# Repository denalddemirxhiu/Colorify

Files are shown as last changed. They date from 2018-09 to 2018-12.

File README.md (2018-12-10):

# Colorify Build Instructions

## Introduction
Colorify is a creative project that allows the user to scan colours in the environment with the help of a colour sensor. The project is meant to detect colours so that they can be used for illustration and graphic design purposes. At the end of this instructive tutorial, we will be able to detect colours in the environment as well as display the colour readings in RGB and HEX format for the user to use freely. Below, the diagrams provide a visual way on how the project works, and how it might be integrated with a database and a mobile application for further development.

### System Diagram
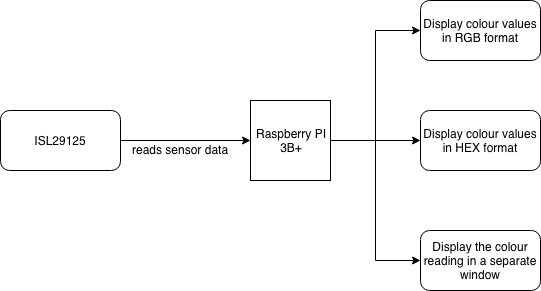
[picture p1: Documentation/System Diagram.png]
System Diagram


### Capstone UML Diagram
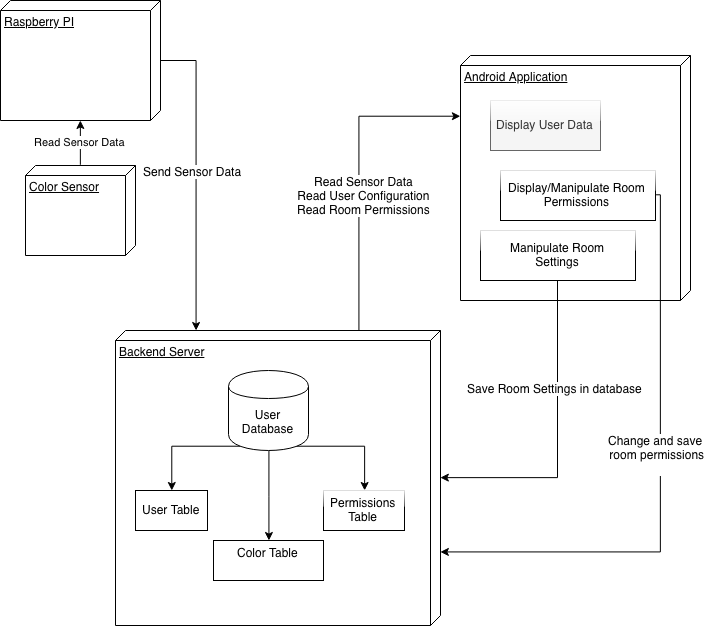
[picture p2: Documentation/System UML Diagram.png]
Capstone UML Diagram


#### Helpful Skills for this project
 - Soldering
 - Raspberry PI knowledge
 - I2C knowledge
 - Python knowledge
 - Breadboarding and wiring knowledge

## Bill of Materials
The devices and components that we will need to complete the project, as well as the sources where they can be found are provided below for reference

| Item Name | Source/Supplier |
|---|---|
| Raspberry Pi 3B+ Starter Kit | CanaKit - https://www.canakit.com/raspberry-pi-3-model-b-plus-starter-kit.html |
| ISL29125 RGB Light Sensor | SparkFun - https://www.sparkfun.com/products/12829 |
| Breadboard Jumper Wires | HaoBase/Amazon - https://www.amazon.ca/gp/product/B01DLKLL6C/ref=ox_sc_act_title_1_1_1?smid=A3F3WC2XXCSM1P&psc=1 |
| Bernzomatic Rosin Core Solder (Lead free) | Canadian Tire - http://www.canadiantire.ca/en/pdp/bernzomatic-rosin-core-solder-0586000p.html#srp |
| Wire Stripper | Ideal/Amazon - https://www.amazon.ca/Ideal-45-120-Stripper-10%C3%9018-Stranded/dp/B000JKWVXA |
| Breadboard | Canada Robotix - http://www.canadarobotix.com/solderless-breadboard/830-point-breadboard |
| Soldering Iron | Canadian Tire - http://www.canadiantire.ca/en/pdp/weller-25w-soldering-iron-kit-0586309p.html#srp |
| Digital Multimeter | Canadian Tire - http://www.canadiantire.ca/en/pdp/autoranging-digital-multimeter-0520052p.0520052.html |
| Clear Acrylic 12"x24" | Johnston Industrial - http://www.johnstonplastics.com/toronto/ |
| 40-pin Stackable Header | Adafruit - https://www.adafruit.com/product/1979 |
| Arduino Stackable Header Kit |  Sparkfun - https://www.sparkfun.com/products/10007 |
| Computer Monitor |  Bestbuy - https://www.bestbuy.ca/en-ca/product/hewlett-packard-hp-21-5-fhd-60hz-7ms-gtg-ips-led-monitor-22vc-black-22vc/10514441.aspx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 |
| Wired Keyboard |  Bestbuy - https://www.bestbuy.ca/en-ca/product/mmnox-mmnox-usb-keyboard-op004-english-op004/10383781.aspx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 |
| Wired Mouse | Bestbuy - https://www.bestbuy.ca/en-ca/product/rapoo-optical-mouse-n1130-white/12966363.aspx? |

Note: The Raspberry Pi 3B+ Starter Kit comes with everything you need such as:
 - Standard Power Supply
 - 16 GB microSD card
 - Black enclosure
 - microSD USB adapter
 - HDMI Cable

If you would like to purchase the above items separately make sure they are bought from a reliable source!

For a more detailed bill of materials with the component prices, sources, part numbers you can click [here](https://github.com/denalddemirxhiu/Colorify/blob/master/Documentation/Colorify%20Budget.xlsx). The total amount of money needed to be spent for this project is about $230 (CAD).

## Time Commitment
This project should not take more than a weekend to be completed after all the components have been gathered. Overall, it should take about 5-7 hours to complete (considering that the PCB has been printed successfully, otherwise the PCB should take about a half-day to be printed). This can be divided in these steps:
 - Raspberry PI setup (2 - 3 hours)
 - Sensor Soldering (30 mins)
 - PCB Soldering with stackable headers (45 mins)
 - Enclosure printing (laser cutting) and assembly (45 mins)
 - Putting it all together (1 hour)
 - Verifying that everything works (30 mins)

## Setting up the Raspberry PI 
For this portion you will need a monitor compatible with HDMI, a wired keyboard (USB) and a wired mouse (USB).
 1. Download the latest version of Raspbian. The image for flashing the Raspbian OS in the Raspberry PI can be found [here](https://www.raspberrypi.org/downloads/raspbian/)
 2. Format the microSD card by plugging it in your computer of choice and use the software found [here](https://www.sdcard.org/downloads/formatter_4/index.html)
 3. Use a software such as [Etcher](https://www.balena.io/etcher/) or [Win32DiskImager](http://sourceforge.net/projects/win32diskimager/) to flash the OS image to the microSD card.
 4. After this process has been finished successfully plug the microSD card in the Raspberry PI 3B+, connect the HDMI cable, the mouse, and the keyboard and power the device on.
 5. After finishing the setup and while on the Desktop we need to change the I2C and VNC interfaces to enabled. This can be done by going to the Start Menu->Preferences->Raspberry Pi Configuration->Interfaces, then set VNC to enabled and I2C to enabled
 
 After these steps have been followed carefully, we can move on to the mechanical assembly.
 
## Mechanical Assembly
To get started, we need to solder the pins to the ISL29125 RGB Light sensor. To do so we need to have 5 pins for each of the holes in the sensor and we need to have the soldering equipment ready. The soldering process needs to be careful as to not short any of the pins with each other which damage the sensor. After the pins have been soldered to the sensor, it should look something like this:

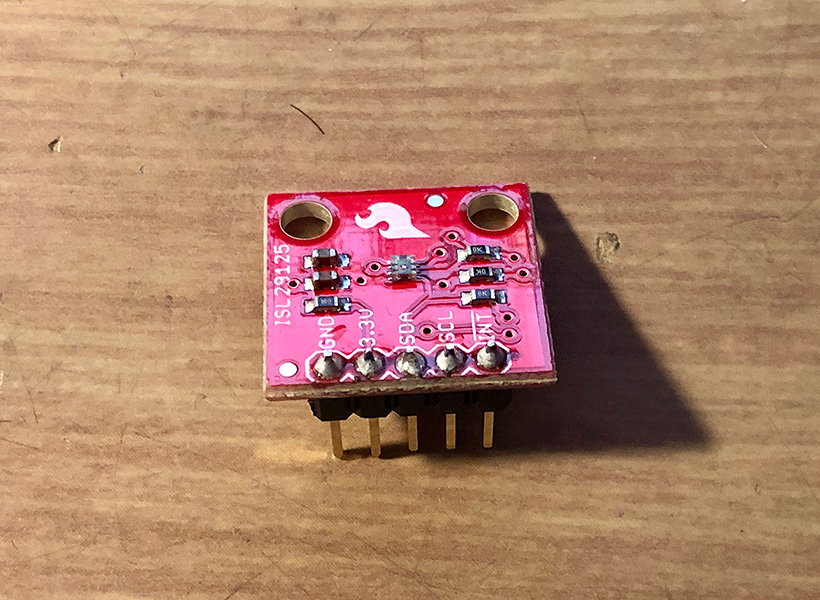
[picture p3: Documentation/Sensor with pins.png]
Sensor Soldered


Secondly, we need to connect the sensor to the Raspberry PI 3B+ to test if it works properly. It is a good idea to power down the Raspberry PI before continuing with this step. First, we place already soldered sensor in the breadboard. Using [this](https://www.theengineeringprojects.com/wp-content/uploads/2018/07/introduction-to-raspberry-pi-3-b-plus-2.png) diagram, we are going to make the appropriate connections from the sensor to the pin headers of the Raspberry PI. For the connections we are going to use the Male-to-Female jumper wires. Since the sensor has labeled pins, we are going to make these connections:
 - PIN 1 (3.3V) of the Raspberry PI should be connected to the pin labeled as 3.3V in the sensor
 - PIN 6 (GND) of the Raspberry PI should be connected to the pin labeled as GND in the sensor
 - PIN 3 (SDA) of the Raspberry PI should be connected to the pin labeled as SDA in the sensor
 - PIN 5 (SCL) of the Raspberry PI should be connected to the pin labeled as SCL in the sensor
 
After the appropriate connections have been made, the wiring should look something like this:

Sensor Wiring

After powering on the Raspberry PI we need to verify that the sensor is being recognized. With the wiring still in place launch the terminal window and type this command:

      sudo i2cdetect -y 1
 
The command will display the sensor in a table like this:
i2cDetect

NOTE: If you don't see the sensor's I2C address in the table (0x44), then verify the connections, verify that I2C Interface is enabled, and as a final resort restart the Raspberry PI.

After all the steps in this section have been verified, you can move on to the next step.

## PCB Soldering
The PCB design used to print the PCB can be found [here](https://github.com/denalddemirxhiu/Colorify/blob/master/Documentation/ISL29125.fz.fzz). The design was made using [Fritzing](http://fritzing.org/home/). To print the PCB you need to convert the provided files into Gerber files and send them to any production facility, as the files are industrially universal.

After the PCB has been printed, we are going to solder the 5 pin stackable header, and the 20 pin stackable header into the PCB. Since none of the stackable headers we have is 5-pin we are going to break one of them into a 5-pin, which can easily be done using a set of pliers. After we do that, we are going to solder the VIAs (small holes with connections on both sides). To do that we are going to use some hookup wire, which we are going to strip and place in the VIAs. After verifying that the VIAs have been soldered, we can insert the stackable headers in the appropriate pins. The 5-pin header is going to be inserted in the side where the labels are found (GND, 3.3V, SDA, SCL). The 40-pin header is going to be inserted on the other side with the pins facing the side the labels are found. After the pins have been soldered we can verify if the connections have been correctly made by using a multimeter. After all the work has been finished the PCB should look something like this:

### PCB Soldered Front
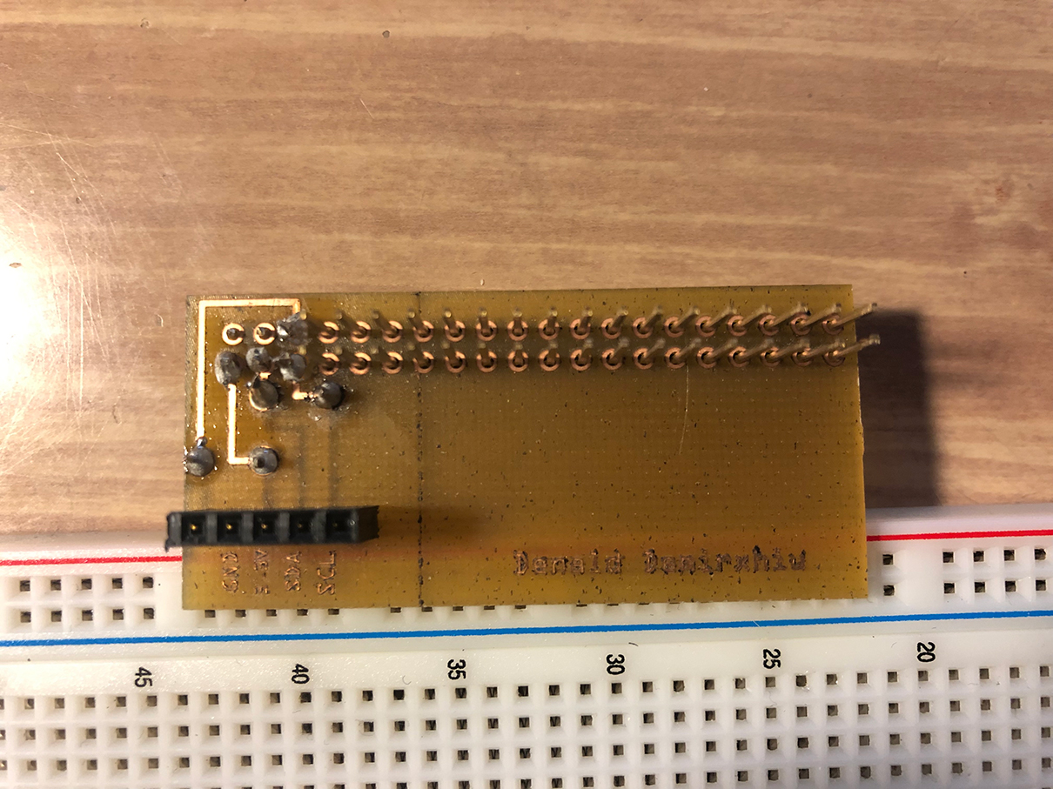
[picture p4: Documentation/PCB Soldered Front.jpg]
PCB Front


### PCB Soldered Back
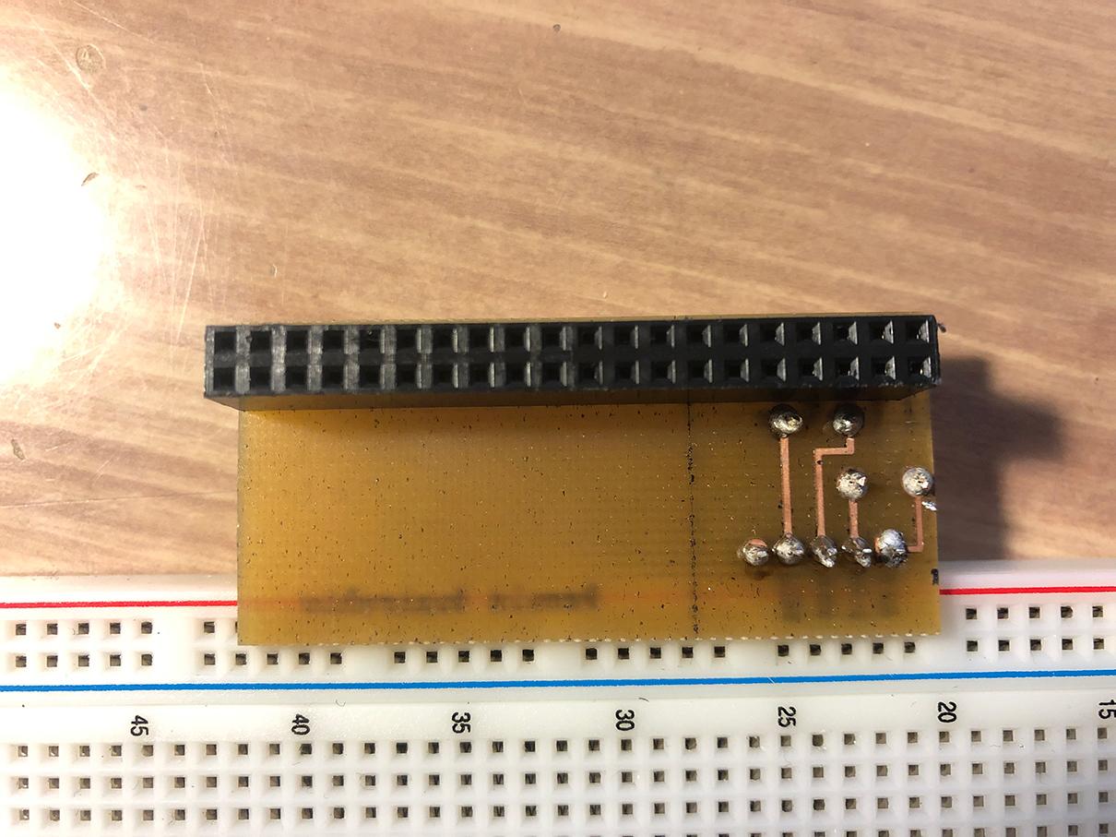
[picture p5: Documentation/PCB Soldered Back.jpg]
PCB Back


## Power Up
After the PCB has been soldered correctly and the sensor has been verified to work with the Raspberry PI, it is time for the power up portion. With the Raspberry PI powered off, the PCB is going to be mounted on the Raspberry PI using the 40-pin stackable header and the sensor is going to be mounted on the 5-pin header on the PCB. After the mounting process is done it should look something like this:

Mounted PCB Sensor

The case that comes with the Raspberry PI 3B+ can fit the PCB board mounted in it. For that reason we don't need to make any specific enclosure for it.

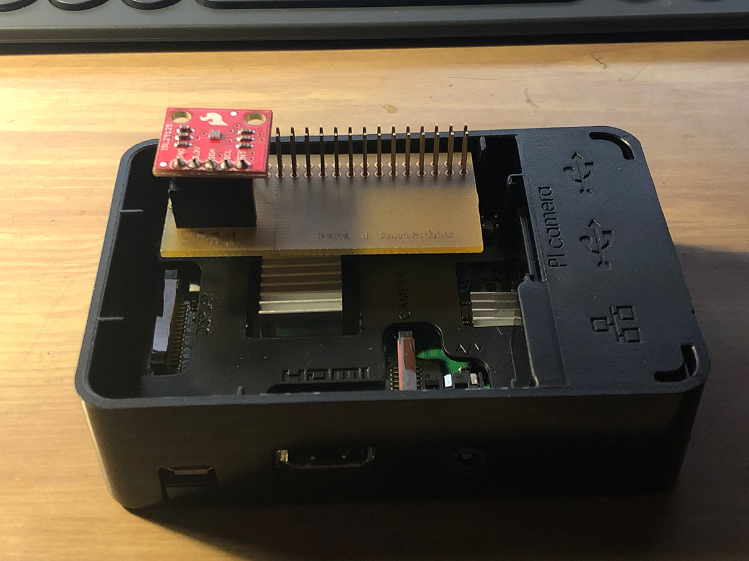
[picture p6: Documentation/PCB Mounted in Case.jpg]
Case with Sensor


After the PCB and the sensor is mounted on the board, it can be powered up and verified that the Raspberry PI recognizes the sensor using the same i2cdetect command as above:

       sudo i2cdetect -y 1

Using the supplied script that can be downloaded from [here](https://github.com/denalddemirxhiu/Colorify/blob/master/Documentation/readSensor.py), you can test the sensor reading actual colour values from the environment. The code uses Python 3 and can be compiled and run using the default python editor in the Raspberry PI, Thonny. If everything has been done correctly you should see an output on the screen like this:

Sensor Output

Note: For the sensor to read different colour values you might want to use a plastic piece of paper (preferrably with colour), however if it is transparent you can use a Sharpie with some different colours to simulate different colour readings. This is one way to test if the sensor is reading values correctly

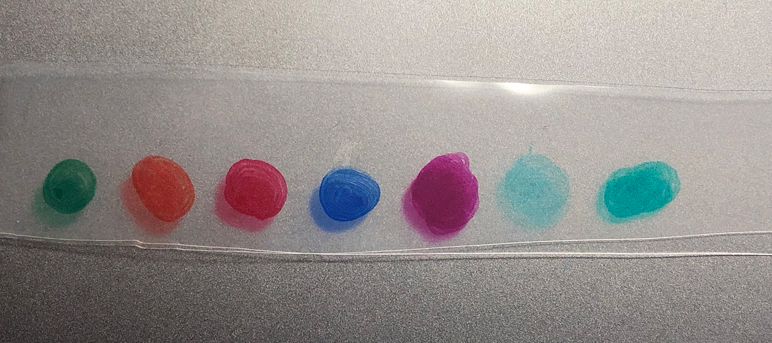
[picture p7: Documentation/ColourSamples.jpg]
Colour samples


## Enclosure

The enclosure for this project does not require any custom case to be made. In fact the case that comes with the Raspberry PI 3B+ can hold the PCB and the sensor intact. The only part that is needed for this enclosure is the top part which ensures that the sensor is kept intact with no contact to materials that might damage it. The enclosure also requires a set of 4 clamps that hold everything together. Both the top enclosure sheets and the clamps are made of acrylic and can easily be laser cut in a matter of minutes. The file for the top enclosure sheets can be found [here](https://github.com/denalddemirxhiu/Colorify/blob/master/Documentation/Top%20Case%20Design%20Files.cdr) and the file for the clamps can be found [here](https://github.com/denalddemirxhiu/Colorify/blob/master/Documentation/Case%20Clamps.cdr). Both designs were made with CorelDraw X6.

The top enclosure part has 5 acrylic frames and one acrylic top that can be stacked together. To glue the components together you might use any transparent glue that you can think of, but if you can find some Liquid Cement for plastic that would work too. After the acrylic sheets have been stacked together and have been glued, the top part of the case should look something like this:

### Acrylic Top
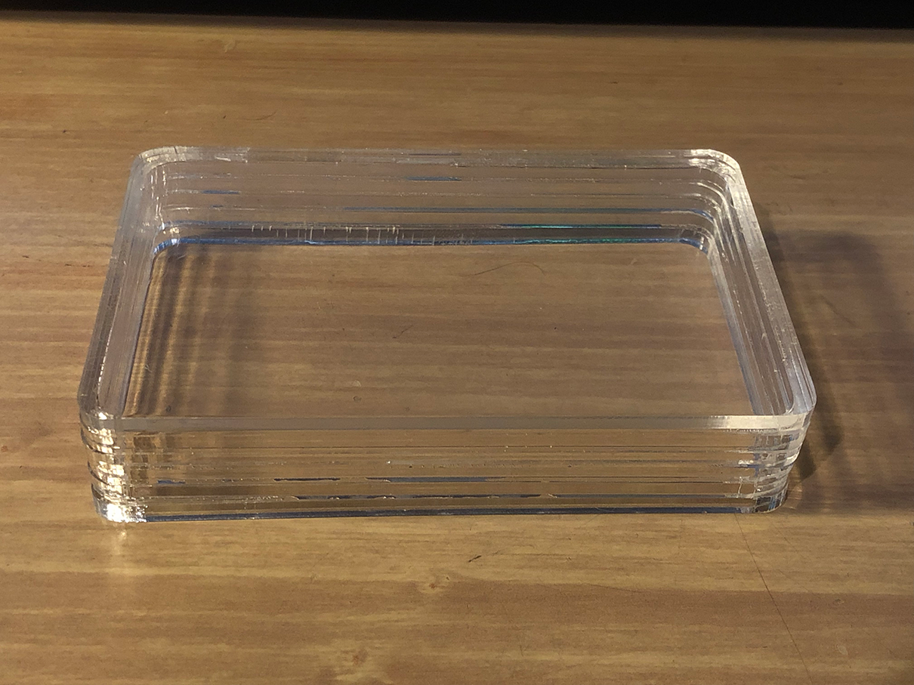
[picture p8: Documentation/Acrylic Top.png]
Top Case


## Finishing it up
By now the Raspberry PI should be in its black case that came with the Starter Kit. The PCB with the mounted sensor, will be inserted into the GPIO pins of the Raspberry PI. Next the acrylic top will be placed on the top of the case with the 4 clamps inserted on each side to support the enclosure. After all the processes above these should be the final results:

### Case with Acrylic sheets on top
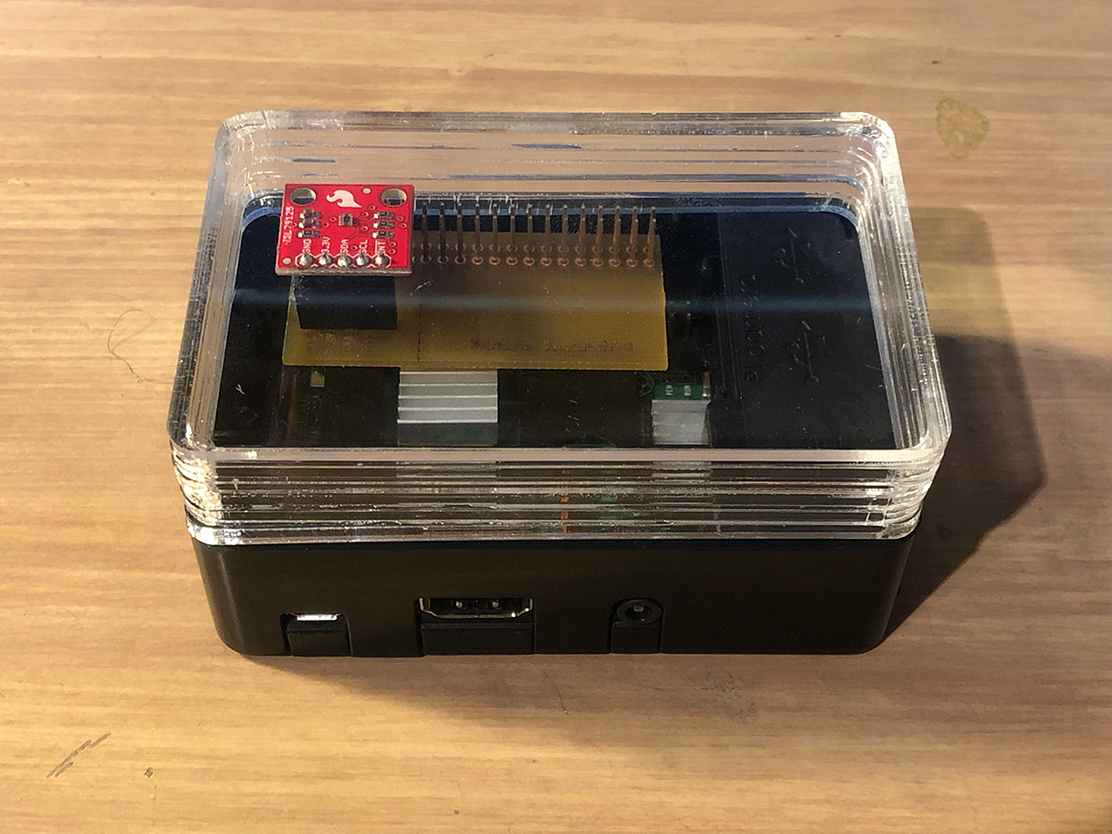
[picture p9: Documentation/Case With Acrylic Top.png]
Completed Case


### Completed Case
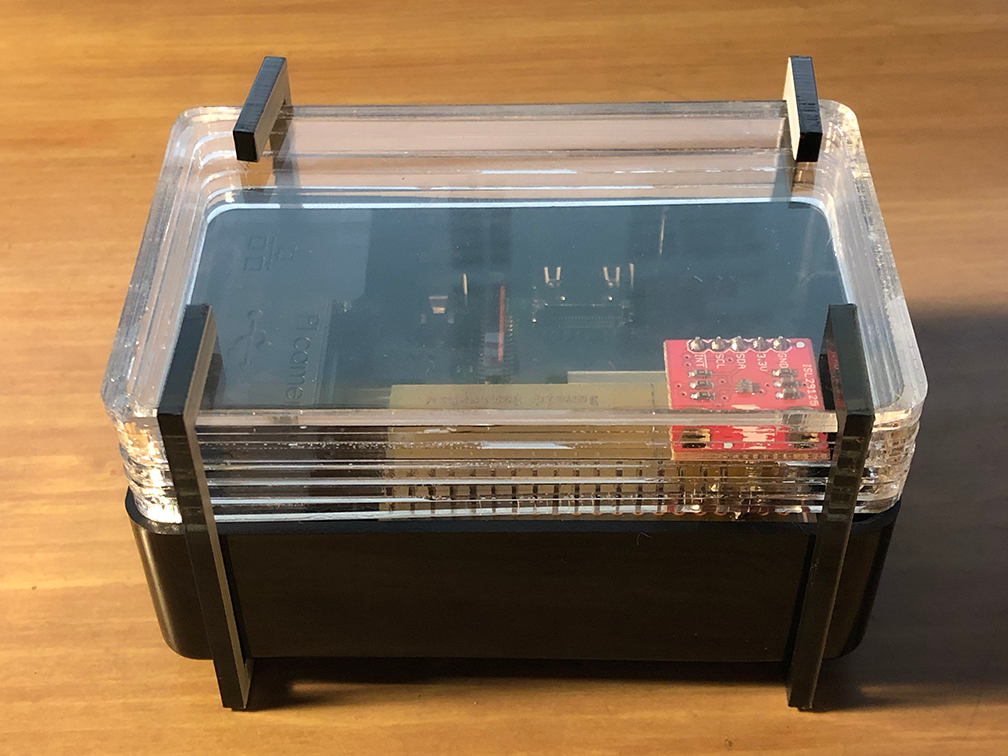
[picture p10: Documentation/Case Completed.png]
Completed Case with Clamps


## Testing
It is useful to test the hardware before testing the software side of the project. First when finishing the soldering of the PCB it is a good idea to check each connection between the appropriate pins. This part of the testing process can be performed using any conductive wire inserted in the stackable header for the pins we are going to use, and a multimeter to test if the connection is correct. If when testing the pins a open circuit is observed then the soldering should be checked and the appropriate measures should be taken.

After testing the hardware we are going to test the software side. With the sensor plugged in the PCB, which should be inserted in the Raspberry PI with the help of the stackable header, we are going to compile and run the provided software for detecting color values and displaying them. 
 - First, we need to check that the Raspberry PI can recognize the sensor mounted on the board. This can be done with the command: `i2cdetect -y 1`. If the sensor is not shown in the table output with the address 0x44 printed on the table, then the Raspberry PI cannot detect it. Make sure that the connections have been checked appropriately, the sensor is not damaged, and the I2C interface has been enabled in the Raspberry PI.
 - Second, compile and run the python code found [here](https://github.com/denalddemirxhiu/Colorify/blob/master/Documentation/readSensor.py) using Thonny. The color readings should be displayed accordingly in RGB and HEX format in the console, while the color readings should also be displayed in a separate window. If there are problems with compilation and running the code, check if the source code is correct, check if Python 3 is correctly installed in the Raspberry PI, and as a last resort restart the device.

## Resources used
 - Intersil Datasheet for ISL29125 found [here](https://www.intersil.com/content/dam/Intersil/documents/isl2/isl29125.pdf)
 - Sparkfun ISL29125 hookup guide found [here](https://learn.sparkfun.com/tutorials/isl29125-rgb-light-sensor-hookup-guide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)
 - Soldering tutorial found [here](https://www.youtube.com/watch?v=Qps9woUGkvI)

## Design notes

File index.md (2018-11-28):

# Colorify
denalddemirxhiu.github.io/Colorify

## November 27th, 2018 (Presentation)
The project was presented to the class today. The presentation can be found [here](https://github.com/denalddemirxhiu/Colorify/blob/master/Documentation/Colorify%20Presentation.pptx)

### Budget Update
There has been no budget update as of this date. The budget can be viewed [here](https://github.com/denalddemirxhiu/Colorify/blob/master/Documentation/Colorify%20Budget.xlsx)

### Project Schedule Update
The progress of the project has been going on schedule. There have been no setbacks. The next milestone is the build instructions. The project schedule can be viewed [here](https://github.com/denalddemirxhiu/Colorify/blob/master/Documentation/Capstone%20Gantt%20Schedule.mpp)

## November 20th, 2018 (Case Design)

### Designed and laser cut the acrylic top case
Since the ISL29125 sensor mounted on the PCB fits perfectly on the case that came with the Raspberry Pi 3B+, I did not have to design a case from scratch. However I needed to design the top part for the case to completely enclose the sensor without affecting the sensor's ability to obtain readings. The top part of the case was made of acrylic sheets that were laser cut and stacked on top of one another to create a simple clear enclosure. A set of clamps were designed to hold the case in place, but unfortunately due to the Prototype Lab's working hours I couldn't laser cut the clamps.

- The design files for the stacks of acrylic needed to make the top part of the case can be found [here](https://github.com/denalddemirxhiu/Colorify/blob/master/Documentation/Top%20Case%20Design%20Files.cdr)
- The design files for the clamps to hold the case in place can be found [here](https://github.com/denalddemirxhiu/Colorify/blob/master/Documentation/Case%20Clamps.cdr)

#### Acrylic Case
Acrylic Top Case

The case

### Completed Case with clamps

The completed case

### Budget Update
There has been no budget update as of this date. The project budget can be viewed [here](https://github.com/denalddemirxhiu/Colorify/blob/master/Documentation/Colorify%20Budget.xlsx)

### Project Schedule Update
The progress of the report has been going on schedule. This week the top part of the acrylic case was properly designed, laser cut and assembled. Next week the presentations are due and the following weeks the build instructions should be ready. The project schedule can be viewed [here](https://github.com/denalddemirxhiu/Colorify/blob/master/Documentation/Capstone%20Gantt%20Schedule.mpp)

## November 13th, 2018

### PCB Soldered and Mounted on the board
The PCB was re-designed, updated, printed and then soldered with the stackable headers in the respective places. The PCB was checked for problems with a multimeter, the sensor was checked if it was working with the PCB mounted on the Raspberry PI, and verified that the program worked while the sensor was mounted on the PCB. This can be seen in the following pictures:

PCB with the Sensor

PCB mounted on the Raspberry Pi

### Sensor Readings and Output
Using Python 3 the sensor readings were obtained and printed on the terminal in RGB format and in HEX format. The colour readings from the sensor are displayed in a window with the respective colour. The sensor readings are not fully accurate because the way that the Red, Green, and Blue photoresistors are placed in the sensor appear to be in a box array where blue and red are always adjacent to each-other, but the green photoresistors are all together. The datasheet also provided this explanation to why the colour readings of the green photoresistors are the most accurate, while the red and blue ones are not always accurate. Furthermore, the sensor is affected by light intensity from direct light coming from a light source. One solution to this might be using an acryllic case that reflects some of the light and lets a portion of the light hit the sensor, but that is not definitive. More research has to be done in that matter. 

The respective pages from the datasheet that display information on this matter are 1, 5, and 15. The datasheet can be viewed [here](https://www.intersil.com/content/dam/Intersil/documents/isl2/isl29125.pdf)

#### Colour samples used
These are colour samples I made to demonstrate the sensor reading colours.

ColourSamples

#### Displaying Color Readings in the Terminal and the Window
Displaying Colour Readings

### Reading the sensor data
To read the sensor data I used the open-source code obtained from [here](https://github.com/bhaskar-anil429/ISL29125/blob/master/ISL29125.py) and modified it to fit my needs. The problem with my sensor was that there was no library to read data from it; the resources from the company that produced the sensor were scarce. The only provided libraries were for Arduino, which are not compatible with the Raspberry PI. Therefore, I used [bhaskar-anil429](https://github.com/bhaskar-anil429)'s source code to work with. I tested the code first and after proving that it worked I made the necessary changes to fit the needs of my project. The program that I designed reads the color values continuously and prints them in a HEX and RGB format, as well as displaying them on another window. The source code for the Python script can be viewed [here](https://github.com/denalddemirxhiu/Colorify/blob/master/Documentation/readSensor.py)

### Budget Update
There has been no budget update since I have not ordered any new parts. Everything has been kept track of and reported properly. The project budget can be viewed [here](https://github.com/denalddemirxhiu/Colorify/blob/master/Documentation/Colorify%20Budget.xlsx)

### Project Schedule Update
The project is going on schedule as of this week. There were some drawbacks last week when trying to solder the designed PCB, but when carefully examining it, the connections were done incorrectly. The PCB was re-designed, updated, printed and then soldered on November 12, 2018. The PCB was checked for problems with a multimeter, the sensor was checked if it was working with the PCB placed on the Raspberry PI and verified that the program worked while the sensor was mounted on the PCB. In the next few weeks, the enclosure of the completed project is due, the presentation needs to be prepared for and the final results of the project need to be made, such as the build instructions. The project schedule can be viewed [here](https://github.com/denalddemirxhiu/Colorify/blob/master/Documentation/Capstone%20Gantt%20Schedule.mpp)

## November 6th, 2018

### Updated PCB Design
Today the PCB vias were soldered, but when asked for feedback I realized that the connections on the PCB were upside down. The PCB design was updated on the Fritzing file, the files were sent to the prototype lab and they were updated on the Documentation folder in the repository. Below are the pictures of the soldered PCB vias on the improperly designed PCB and the new Updated PCB design:

#### Soldered vias on the improperly designed PCB
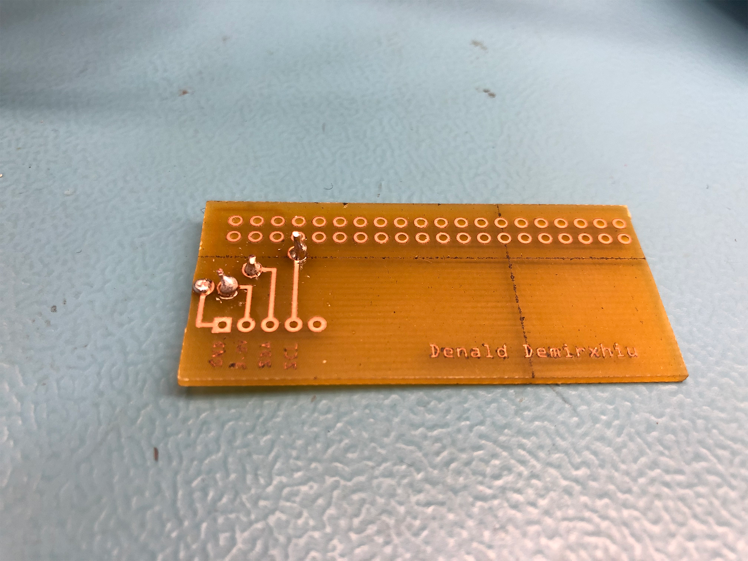
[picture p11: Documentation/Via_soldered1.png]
Via Soldered Top


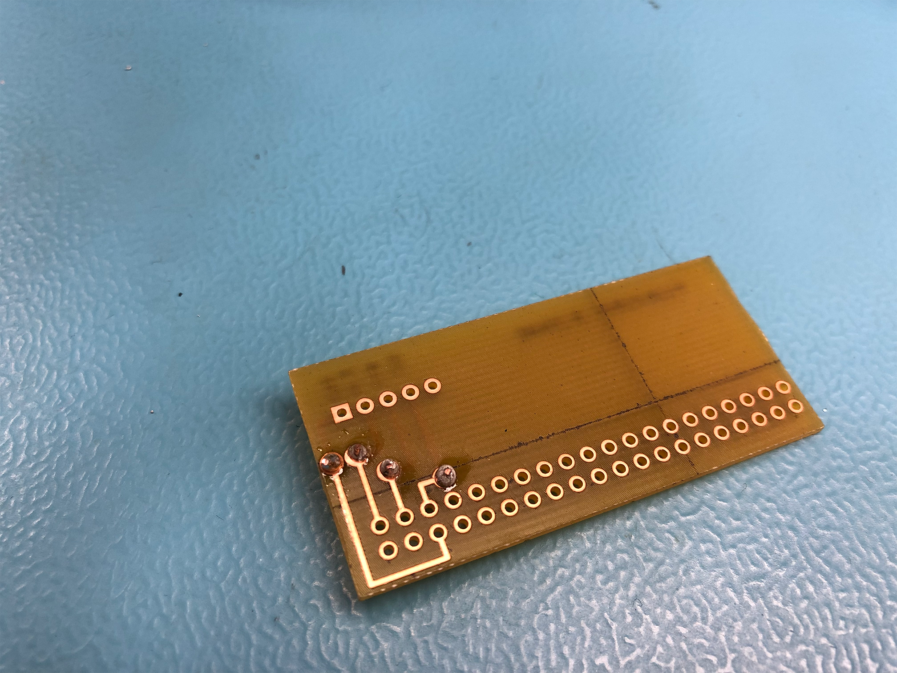
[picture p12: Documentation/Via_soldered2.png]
Via Soldered Bottom


#### Updated PCB Design
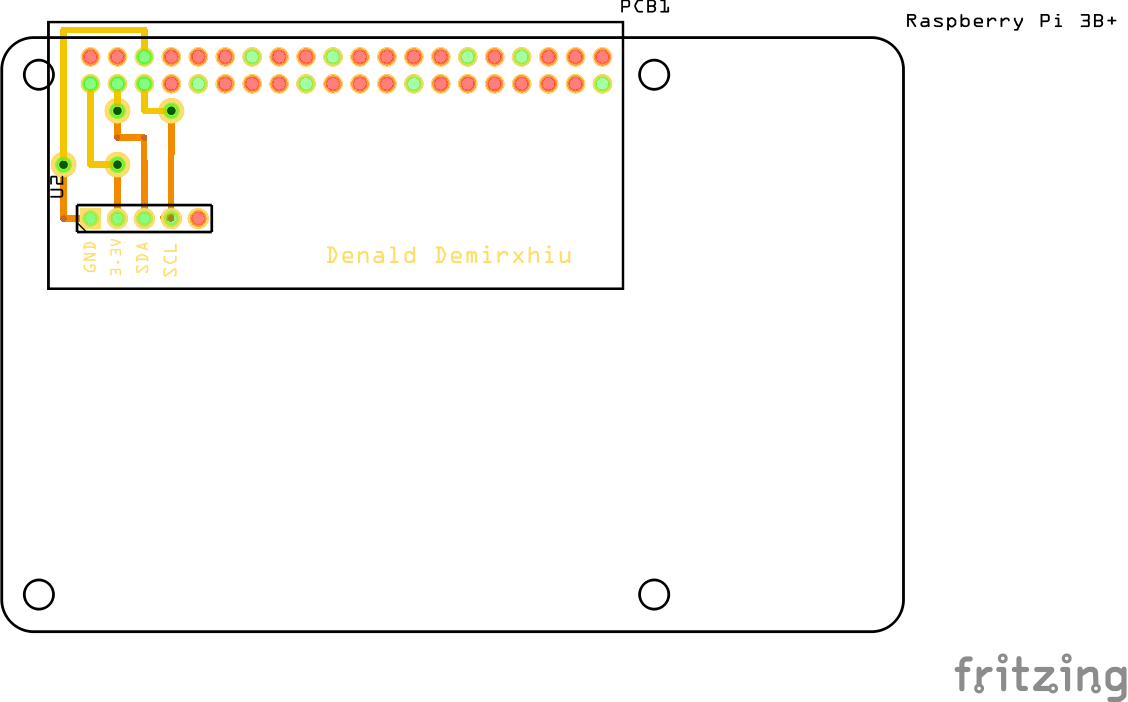
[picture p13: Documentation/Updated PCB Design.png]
Updated PCB Design


### Budget Update
There has been no budget update since I have not ordered any new parts. The project budget can be viewed [here](https://github.com/denalddemirxhiu/Colorify/blob/master/Documentation/Colorify%20Budget.xlsx)

### Project Schedule Update
As of today we are one week behind on schedule since the PCB was not soldered. The updated design PCB will be soldered by Friday November 9th and be ready by next week. Next week is the Power Up Milestone, therefore there should be a Project Report update and the Raspberry Pi should be reading data from my sensor. The project schedule can be viewed [here](https://github.com/denalddemirxhiu/Colorify/blob/master/Documentation/Capstone%20Gantt%20Schedule.mpp)

## October 23rd, 2018

### PCB Designed
At this point the PCB design was finished and the gerber files were sent to the Prototype Lab. 
Here are some images displaying the fritzing file work on the breadboard, schematic and PCB design:

#### Breadboard
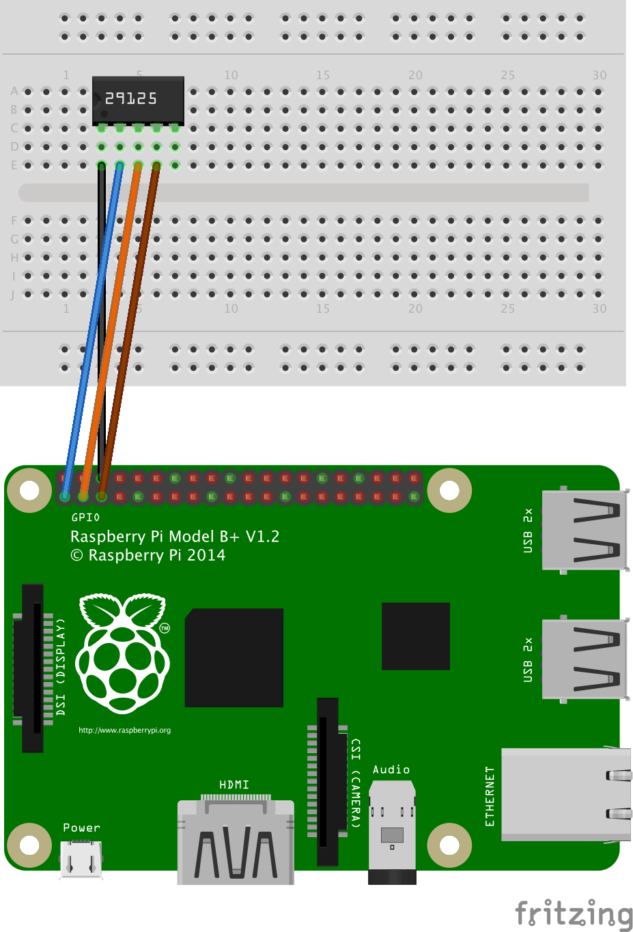
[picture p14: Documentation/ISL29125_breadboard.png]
Breadboard


#### Schematic
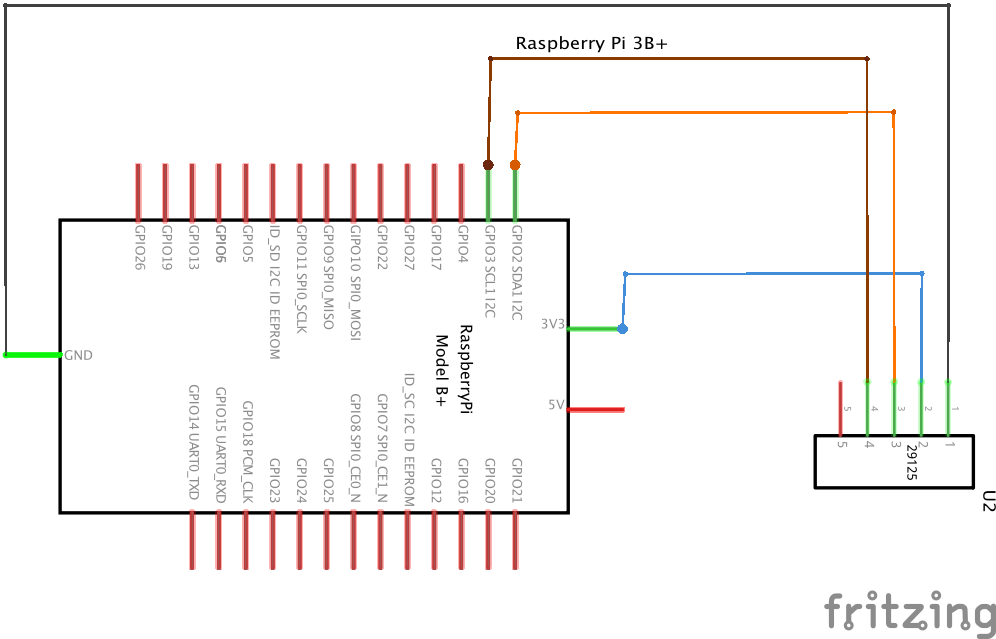
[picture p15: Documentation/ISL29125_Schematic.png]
Schematic


#### PCB Design
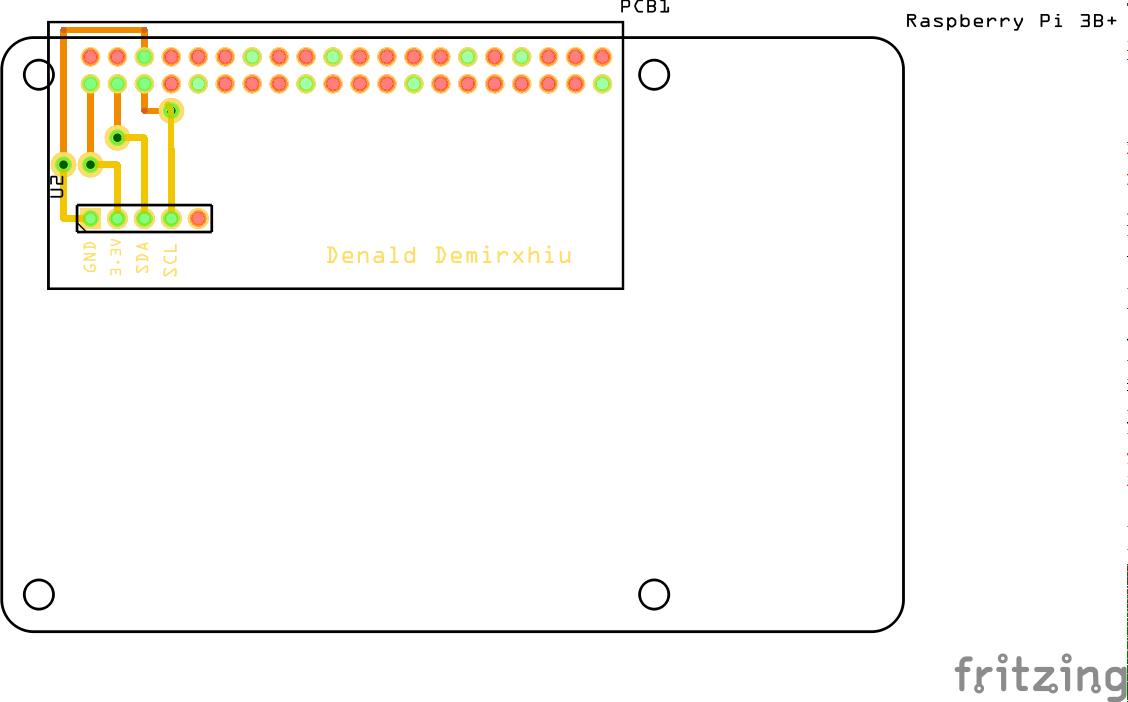
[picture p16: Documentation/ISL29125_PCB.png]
PCB Design


### Budget Update
There has been no budget update since I have not ordered any new parts. The project budget can be viewed [here](https://github.com/denalddemirxhiu/Colorify/blob/master/Documentation/Colorify%20Budget.xlsx)

### Project Schedule Update
According to the project schedule we have completed the PCB design on time therefore we are on schedule. Next week is the PCB soldering Milestone therefore there should be updates next week. The project schedule can be viewed [here](https://github.com/denalddemirxhiu/Colorify/blob/master/Documentation/Capstone%20Gantt%20Schedule.mpp)

## October 23rd, 2018

### Breadboarding Milestone
  At this point the Raspberry Pi was hooked up to the sensor via jumper wires. Below are the images that provide proof that the Raspberry Pi was connected to the sensor and it recognized the sensor using the i2cdetect command.
  The sensor was connected to the Rasberry Pi using the following pins:  
- PIN 1 (3.3V) - connected to 3.3 V pin in the sensor with an orange jumper wire  
- PIN 3 (SDA1) - connected to SDA pin in the sensor with a blue jumper wire  
- PIN 5 (SCL1) - connected to the SCL pin in the sensor with a brown jumper wire  
- PIN 6 (GND) - connected to the GND pin in the sensor with a black jumper wire  
  
### Sensor Hookup (Breadboard wiring)
  Raspberry Pi Breadboard Sensor Hookup
  
### i2cDetect Proof that shows the address of the sensor 0x44
  Raspberry Pi i2cdetect proof
  
### Project Schedule Update
  We just finished the Breadboarding milestone which shows that based on the project planned schedule I am currently on schedule. For the moment I am working to create the diagram for the PCB in Fritzing which should be completed by next week. As soon as I get the PCB design completed I will send the files to Vlad and Kelly in the Prototype Lab (J233). The project schedule can be viewed [here](https://github.com/denalddemirxhiu/Colorify/blob/master/Documentation/Capstone%20Gantt%20Schedule.mpp)
  
### Budget Update
  Currently there are no changes to the budget, except for the parts that have arrived. All the parts that I ordered have arrived and I am not planning to buy any extra parts. The project budget can be viewed [here](https://github.com/denalddemirxhiu/Colorify/blob/master/Documentation/Colorify%20Budget.xlsx) 

### Resources used to wire and connect to the sensor
  - Raspberry Solutions website that shows the pinout of the Raspberry Pi 3B+ can be found [here](https://www.raspberry-solutions.com/connect-sensor-to-raspberry-pi/)  
  - Sparkfun guide that shows the step by step tutorial on how to hookup the ISL29125 sensor can be found [here](https://learn.sparkfun.com/tutorials/isl29125-rgb-light-sensor-hookup-guide/hardware-overview)
  
## October 16th, 2018
### Group Pseudo Code Assignment
  Met with the first year students and helped them write the pseudo code for my third year capstone project. Provided the System UML Diagram which can be viewed [here](https://github.com/denalddemirxhiu/Colorify/blob/master/Documentation/System%20UML%20Diagram.pdf)

## October 9th, 2018

### Reading week holiday
  
## October 2nd, 2018
### Proof of purchase of Raspberry Pi:
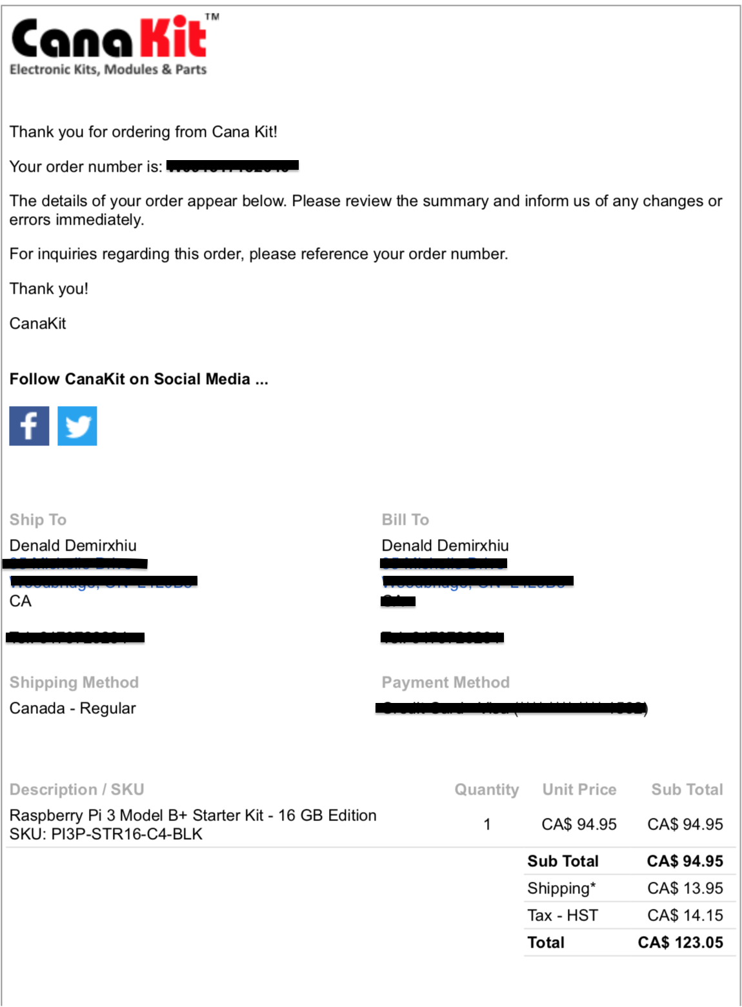
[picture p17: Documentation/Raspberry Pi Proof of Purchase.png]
Raspberry Pi Proof of Purchase
  

### Proof of purchase of ISL29125 Colour Sensor:
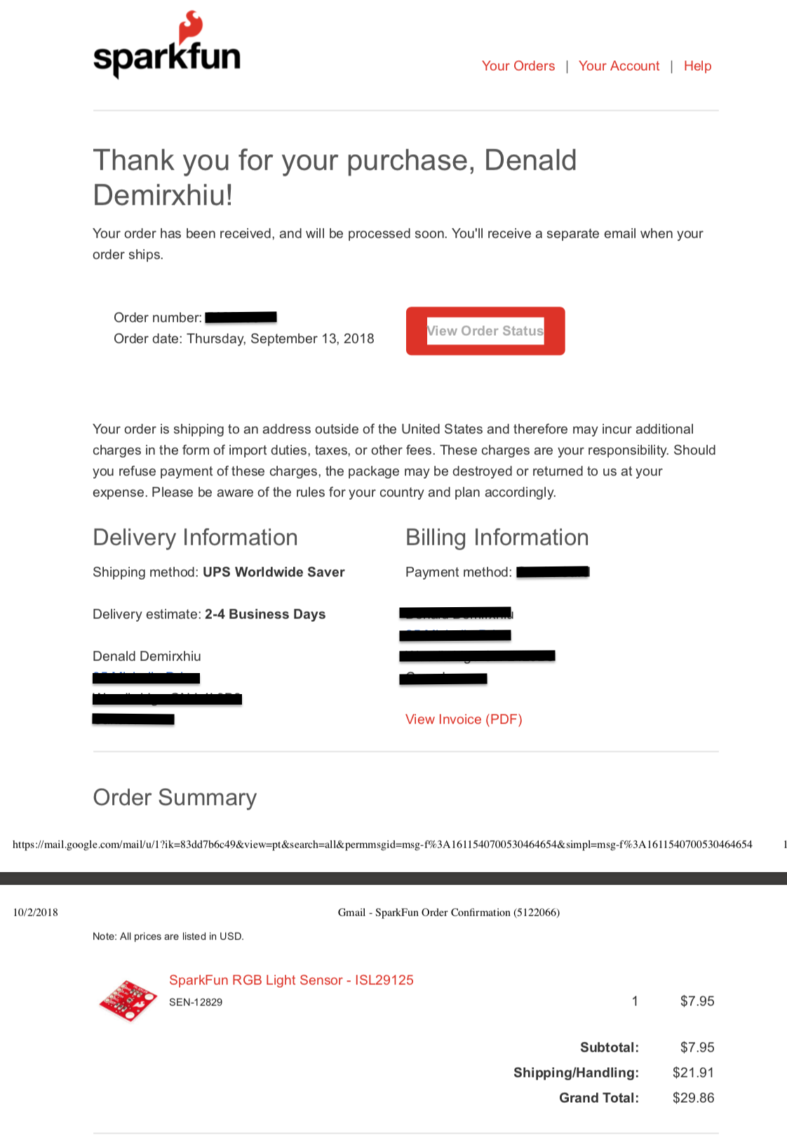
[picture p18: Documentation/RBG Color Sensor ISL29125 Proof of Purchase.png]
ISL29125 Colour Sensor Proof of Purchase
  
  
## September 25th, 2018
  Provided Budget. Can be viewed [here](https://github.com/denalddemirxhiu/Colorify/blob/master/Documentation/Colorify%20Budget.xlsx)

## September 18th, 2018
  Compiled and completed Project Schedule. Can be viewed [here](https://github.com/denalddemirxhiu/Colorify/blob/master/Documentation/Capstone%20Gantt%20Schedule.mpp)
  
## September 11th, 2018 
  Project proposal finished. Can be viewed [here](https://github.com/denalddemirxhiu/Colorify/blob/master/Documentation/ProjectProposalDenaldDemirxhiu.xlsx)

## September 4th, 2018

### Repository Created
  Welcome


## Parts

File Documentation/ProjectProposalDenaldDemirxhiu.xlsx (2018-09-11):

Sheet: DataEntry
Submission Date | 2018-09-11
Project Name | Colorify
Student Name | Denald Demirxhiu
Project repository | https://github.com/denalddemirxhiu/Colorify
SensorEffector choice | ISL29125 Colour Sensor (0x44)
The database will store | Colour reading values in RGB, HEX and CMYK formats.
The mobile device functionality will include | Getting information from the sensor, having the ability to share the colours to other devices, displaying previous colour readings.
I will be collaborating with the following company/department | I will be collaborating with George Paravantes, Program Coordinator Multimedia Design and Development in the School of Media Studies & Information Technology at Humber College.
My group in the winter semester will include | Jacob Ladan and Marko Javorac.
50 word problem statement | This project will help graphic designers, web designers, and even digital artist input colours into their colour schemes from sorrounding objects. With the RGB colour sensor the user can get this value and use it in their piece of work as they would from a digital colour picker.
100 words of background | Having experience with graphic design, this project gives me the opportunity to identify how the colour sensor works and what it can achieve with further development. The ISL29125 colour sensor obtains RGB readings from the environment with IR rejection allowing the project to operate in environments from sunlight to dark rooms. The documentation of this sensor provides various applications for this product such as smartphones, colour balancing techniques, ambient light color detection/correction, etc. The application I am interested in is the reading of colour from real objects and storing that value in different formats for the use of colour schemes in designing fields.
Current product APA citation | Scribble. (2018, Sep 7). Retrieved from https://scribblepen.com/
Existing research IEEE paper APA citation | X. Huixi and C. Yunhao, "A Technique for Simulating Pseudo Natural Color Images Based on Spectral Similarity Scales," in IEEE Geoscience and Remote Sensing Letters, vol. 9, no. 1, pp. 70-74, Jan. 2012. doi: 10.1109/LGRS.2011.2160710 keywords: {geophysical image processing;geophysical techniques;image colour analysis;image representation;image resolution;natural scenes;remote sensing;spectral analysis;pseudonatural color image simulation;spectral similarity scale;visual interpretation;draped terrain;visual display;nonremote sensing professional users;blue wavelength;inverse dependence;high-resolution satellite;visual spectral band;green band;red band;near-infrared region;true color image;high-resolution image;pseudonatural color composite representation;false color composite image;natural color generator;Image color analysis;Color;Atmospheric modeling;Remote sensing;Libraries;Visualization;FCC;Ground-object spectrum;natural color simulation;remote sensing;spectral similarity scale (SSS)}, URL: http://ieeexplore.ieee.org/stamp/stamp.jsp?tp=&arnumber=5970086&isnumber=6109854
Brief description of planned purchases | Raspberry Pi Model 3B+ Kit, ISL29125 Colour Sensor, LED lights, wire connectors
Solution description | This project's solution will help designers read various colours from real objects using the ISL29125 RGB colour sensor. With the help of the software side the sensor readings will be converted into different formats that will allow for flexibility of use in various design applications.

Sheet: DataBase
Submission Date | Project Name | Student Name | Project repository | SensorEffector choice | The database will store | The mobile device functionality will include | I will be collaborating with the following company/department | My group in the winter semester will include | 50 word problem statement | 100 words of background | Current product APA citation | Existing research IEEE paper APA citation | Brief description of planned purchases | Solution description
43354 | Colorify | Denald Demirxhiu | https://github.com/denalddemirxhiu/Colorify | ISL29125 Colour Sensor (0x44) | Colour reading values in RGB, HEX and CMYK formats. | Getting information from the sensor, having the ability to share the colours to other devices, displaying previous colour readings. | I will be collaborating with George Paravantes, Program Coordinator Multimedia Design and Development in the School of Media Studies & Information Technology at Humber College. | Jacob Ladan and Marko Javorac. | This project will help graphic designers, web designers, and even digital artist input colours into their colour schemes from sorrounding objects. With the RGB colour sensor the user can get this value and use it in their piece of work as they would from a digital colour picker. | Having experience with graphic design, this project gives me the opportunity to identify how the colour sensor works and what it can achieve with further development. The ISL29125 colour sensor obtains RGB readings from the environment with IR rejection allowing the project to operate in environments from sunlight to dark rooms. The documentation of this sensor provides various applications for this product such as smartphones, colour balancing techniques, ambient light color detection/correction, etc. The application I am interested in is the reading of colour from real objects and storing that value in different formats for the use of colour schemes in designing fields. | X. Huixi and C. Yunhao, "A Technique for Simulating Pseudo Natural Color Images Based on Spectral Similarity Scales," in IEEE Geoscience and Remote Sensing Letters, vol. 9, no. 1, pp. 70-74, Jan. 2012. doi: 10.1109/LGRS.2011.2160710 keywords: {geophysical image processing;geophysical techniques;image colour analysis;image representation;image resolution;natural scenes;remote sensing;spectral analysis;pseudonatural color image simulation;spectral similarity scale;visual interpretation;draped terrain;visual display;nonremote sensing professional users;blue wavelength;inverse dependence;high-resolution satellite;visual spectral band;green band;red band;near-infrared region;true color image;high-resolution image;pseudonatural color composite representation;false color composite image;natural color generator;Image color analysis;Color;Atmospheric modeling;Remote sensing;Libraries;Visualization;FCC;Ground-object spectrum;natural color simulation;remote sensing;spectral similarity scale (SSS)}, URL: http://ieeexplore.ieee.org/stamp/stamp.jsp?tp=&arnumber=5970086&isnumber=6109854 | #REF! | Raspberry Pi Model 3B+ Kit, ISL29125 Colour Sensor, LED lights, wire connectors | This project's solution will help designers read various colours from real objects using the ISL29125 RGB colour sensor. With the help of the software side the sensor readings will be converted into different formats that will allow for flexibility of use in various design applications.

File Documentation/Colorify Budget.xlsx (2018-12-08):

Name of the item | Description of the item | Source/Supplier | Part no/id | Quantity | Price per unit(CAD) | Price per unit(USD) | Customs | Shipping | Tax (HST) | Subtotal (CAD) | Owned
Raspberry Pi 3B+ | Raspberry Pi 3B+ Starter Kit including power and HDMI cable, heatsinks, and a 16 GB microSD card | CanaKit - https://www.canakit.com/raspberry-pi-3-model-b-plus-starter-kit.html | BCM2837B0 | 1 | $94.95 | $0.00 | $0.00 | $13.95 | $14.15 | $123.05 | No
ISL29125 Sensor | I2C RGB Light Sensor | SparkFun - https://www.sparkfun.com/products/12829 | SEN-12829 | 1 | $10.27 | $7.95 | $0.00 | $28.30 | $0.00 | $38.57 | No
Electronics Parts Kit | Box of different electronics parts such as cables, wires, capacitors, resistors, transistors | Humber Bookstore | N/A | 1 | $120.00 | $0.00 | $0.00 | $0.00 | $15.60 | $135.60 | Yes
Breadboard Jumper Wires | Pack of 120 jumper wires Male-Male, Male-Female, Female-Female | HaoBase/Amazon - https://www.amazon.ca/gp/product/B01DLKLL6C/ref=ox_sc_act_title_1_1_1?smid=A3F3WC2XXCSM1P&psc=1 | 2ELE37-M3 | 1 | $9.99 | $0.00 | $0.00 | $0.00 | $1.30 | $11.20 | No
Bernzomatic Rosin Core Solder | Lead free 8oz solder, for electrical use | Canadian Tire - http://www.canadiantire.ca/en/pdp/bernzomatic-rosin-core-solder-0586000p.html#srp | 058-6000-8 | 1 | $14.99 | $0.00 | $0.00 | $0.00 | $1.95 | $16.94 | No
Wire Stripper | Ideal 45-120 T Stripper for Solid and Stranded Wires | Ideal/Amazon - https://www.amazon.ca/Ideal-45-120-Stripper-10%C3%9018-Stranded/dp/B000JKWVXA | B000JKWVXA | 1 | $33.45 | $0.00 | $0.00 | $0.00 | $4.35 | $37.80 | Yes
Breadboard | Breadboard with Self-Adhesive (830 Tie Point White) | Canada Robotix - http://www.canadarobotix.com/solderless-breadboard/830-point-breadboard | 0160-PRT | 1 | $4.99 | $0.00 | $0.00 | $8.99 | $0.65 | $14.63 | Yes
Hook Up Wire - Red | Solid Hook Up Wire - 22 Gauge, 100 Foot - Red | Electronix Express / Amazon - https://www.amazon.com/ELECTRONIX-EXPRESS-Solid-Hook-Wire/dp/B00DRGJ08M?s=lamps-light | 2700122RD | 1 | $8.99 | $0.00 | $0.00 | $0.00 | $1.17 | $10.16 | Yes
Hook Up Wire - Black | Solid Hook Up Wire - 22 Gauge, 100 Foot - Black | Electronix Express / Amazon - https://www.amazon.com/dp/B00DRGAQ0I/ref=psdc_495310_t1_B00DRGJ08M | 2700122BK | 1 | $8.25 | $0.00 | $0.00 | $0.00 | $1.17 | $9.32 | Yes
Soldering Iron | Weller 25W Soldering Iron Kit | Canadian Tire - http://www.canadiantire.ca/en/pdp/weller-25w-soldering-iron-kit-0586309p.html#srp | 058-6309-6 | 1 | $39.99 | $0.00 | $0.00 | $0.00 | $5.20 | $45.19 | Yes
Digital Multimeter | Mastercraft Autoranging Digital Multimeter with 2 ranges | Canadian Tire - http://www.canadiantire.ca/en/pdp/autoranging-digital-multimeter-0520052p.0520052.html | 052-0052-2 | 1 | $27.99 | $0.00 | $0.00 | $0.00 | $3.64 | $31.63 | Yes
Clear Acrylic 12"x24" | Clear Acrylic Sheet | Johnston Industrial - http://www.johnstonplastics.com/toronto/ | N/A | 1.5 | $7.18 | $0.00 | $0.00 | $0.00 | $1.40 | $12.17 | No
 |  |  |  |  |  |  |  | TOTAL |  | $486.26
 |  |  |  |  |  |  |  | Total to be purchased |  | $201.93
 |  |  |  |  |  |  |  | Total owned |  | $284.33
 |  |  |  |  |  |  |  | Conversion rate USD to CAD |  | 1.29

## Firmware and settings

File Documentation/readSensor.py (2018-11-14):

# Source code for reading colour data from ISL29125
# Obtained from https://github.com/bhaskar-anil429/ISL29125/blob/master/ISL29125.py
# Modified to fit Colorify Project needs
import smbus
import time
from tkinter import *

# Get I2C bus
bus = smbus.SMBus(1)

# Create a WINDOW
window = Tk()
window.title ("Colour Readings")


# ISL29125 address, 0x44(68)
# Select configuation-1register, 0x01(01)
# 0x0D(13) Operation: RGB, Range: 360 lux, Res: 16 Bits
bus.write_byte_data(0x44, 0x01, 0x05)

time.sleep(1)
# ISL29125 address, 0x44(68)
# Read data back from 0x09(9), 6 bytes
# Green LSB, Green MSB, Red LSB, Red MSB, Blue LSB, Blue MSB

print("Reading colour values and displaying them in a new window\n")

def getAndUpdateColour():
    while True:
        data = bus.read_i2c_block_data(0x44, 0x09, 6)

        # Convert the data
        green = int((data[1] * 256 + data[0])/256)
        red = int((data[3] * 256 + data[2])/256)
        blue = int((data[5] * 256 + data[4])/256)
        hex = "#" + format(red, '02x') + format(green, '02x') + format(blue, '02x')
        
        # Output data to the console RGB and HEX values
        print("RGB(%d %d %d)" % (red, green, blue))
        print("HEX ", hex)
        print()
        
        # Update window Color
        window.configure(bg=hex)
        window.update_idletasks()
        
        time.sleep(2) 
        
# Settinh window size, resizable and the update interval
window.geometry("500x500");
window.resizable(0, 0)
window.after(2000, getAndUpdateColour())
window.mainloop()

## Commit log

2018-09-11 Added Project Proposal
    [ProjectProposalDenaldDemirxhiu.xlsx]
2018-09-18 Added documentation
    Added documentation
    [ProjectProposalDenaldDemirxhiu.xlsx]
2018-09-25 Budget Added
    [Colorify Budget.xlsx]
2018-10-23 Added the i2c detect and Sensor hookup pictures
2018-10-23 Added i2c detect and Breadboard Sensor hookup pictures
2018-10-30 Gerber Files added
2018-11-06 Updated the Fritzing files with fixed PCB design
    [ISL29125.fz.fzz]
2018-11-06 Updated PCB Design
2018-11-06 PCB Vias Soldered
2018-11-13 Added Sensor Reading Proof
2018-11-20 Added Soldered PCB
2018-11-21 Added Case design files and images
2018-11-26 Case Completed with Clamps
2018-12-08 Added Images
    [Colorify Budget.xlsx]
